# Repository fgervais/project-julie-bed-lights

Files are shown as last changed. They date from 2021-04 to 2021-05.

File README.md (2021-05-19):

# RGB LED Strip Controller

## Main Board
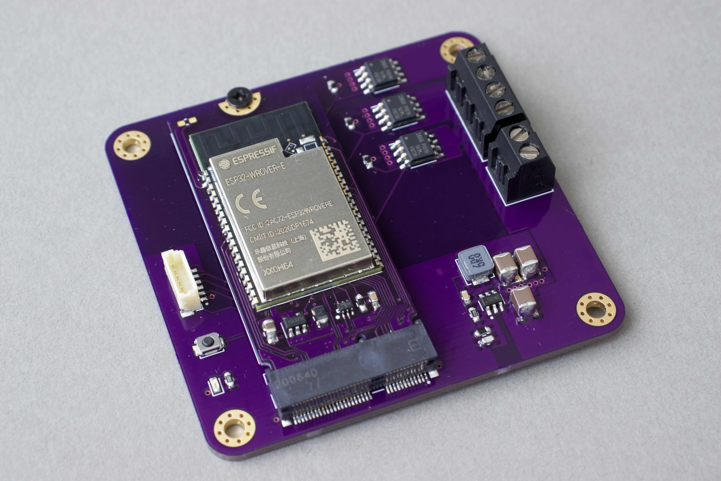
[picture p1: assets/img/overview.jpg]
Overview


## Early Tests with LED Strip
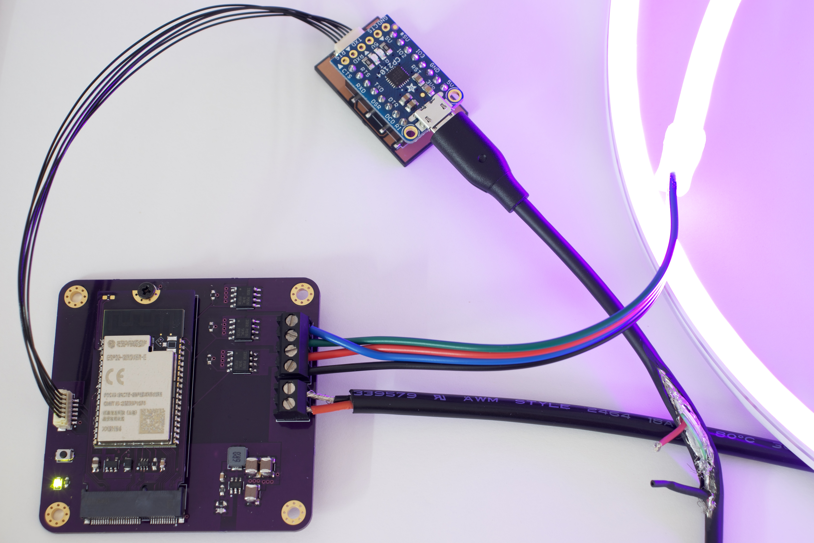
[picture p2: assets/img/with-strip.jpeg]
LED Strip


## Installed
Installed

## App

This project is entirely controlled through the phone app. 

The QR code can be used to get a copy of this Blink project.

Blynk Project | Blynk Project Clone QR
:-------------------------:|:-------------------------:
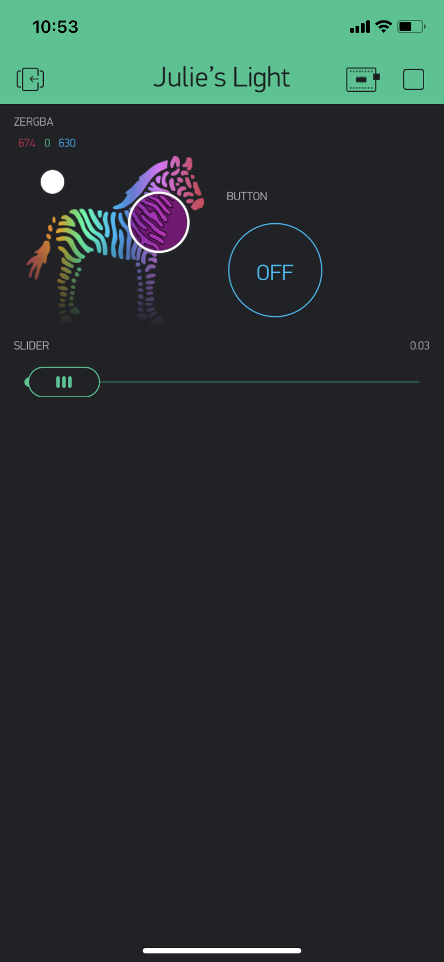
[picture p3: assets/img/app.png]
Blynk Project
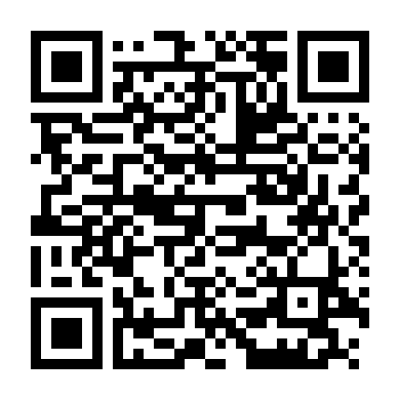
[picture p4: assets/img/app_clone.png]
Blynk Project QR
  |

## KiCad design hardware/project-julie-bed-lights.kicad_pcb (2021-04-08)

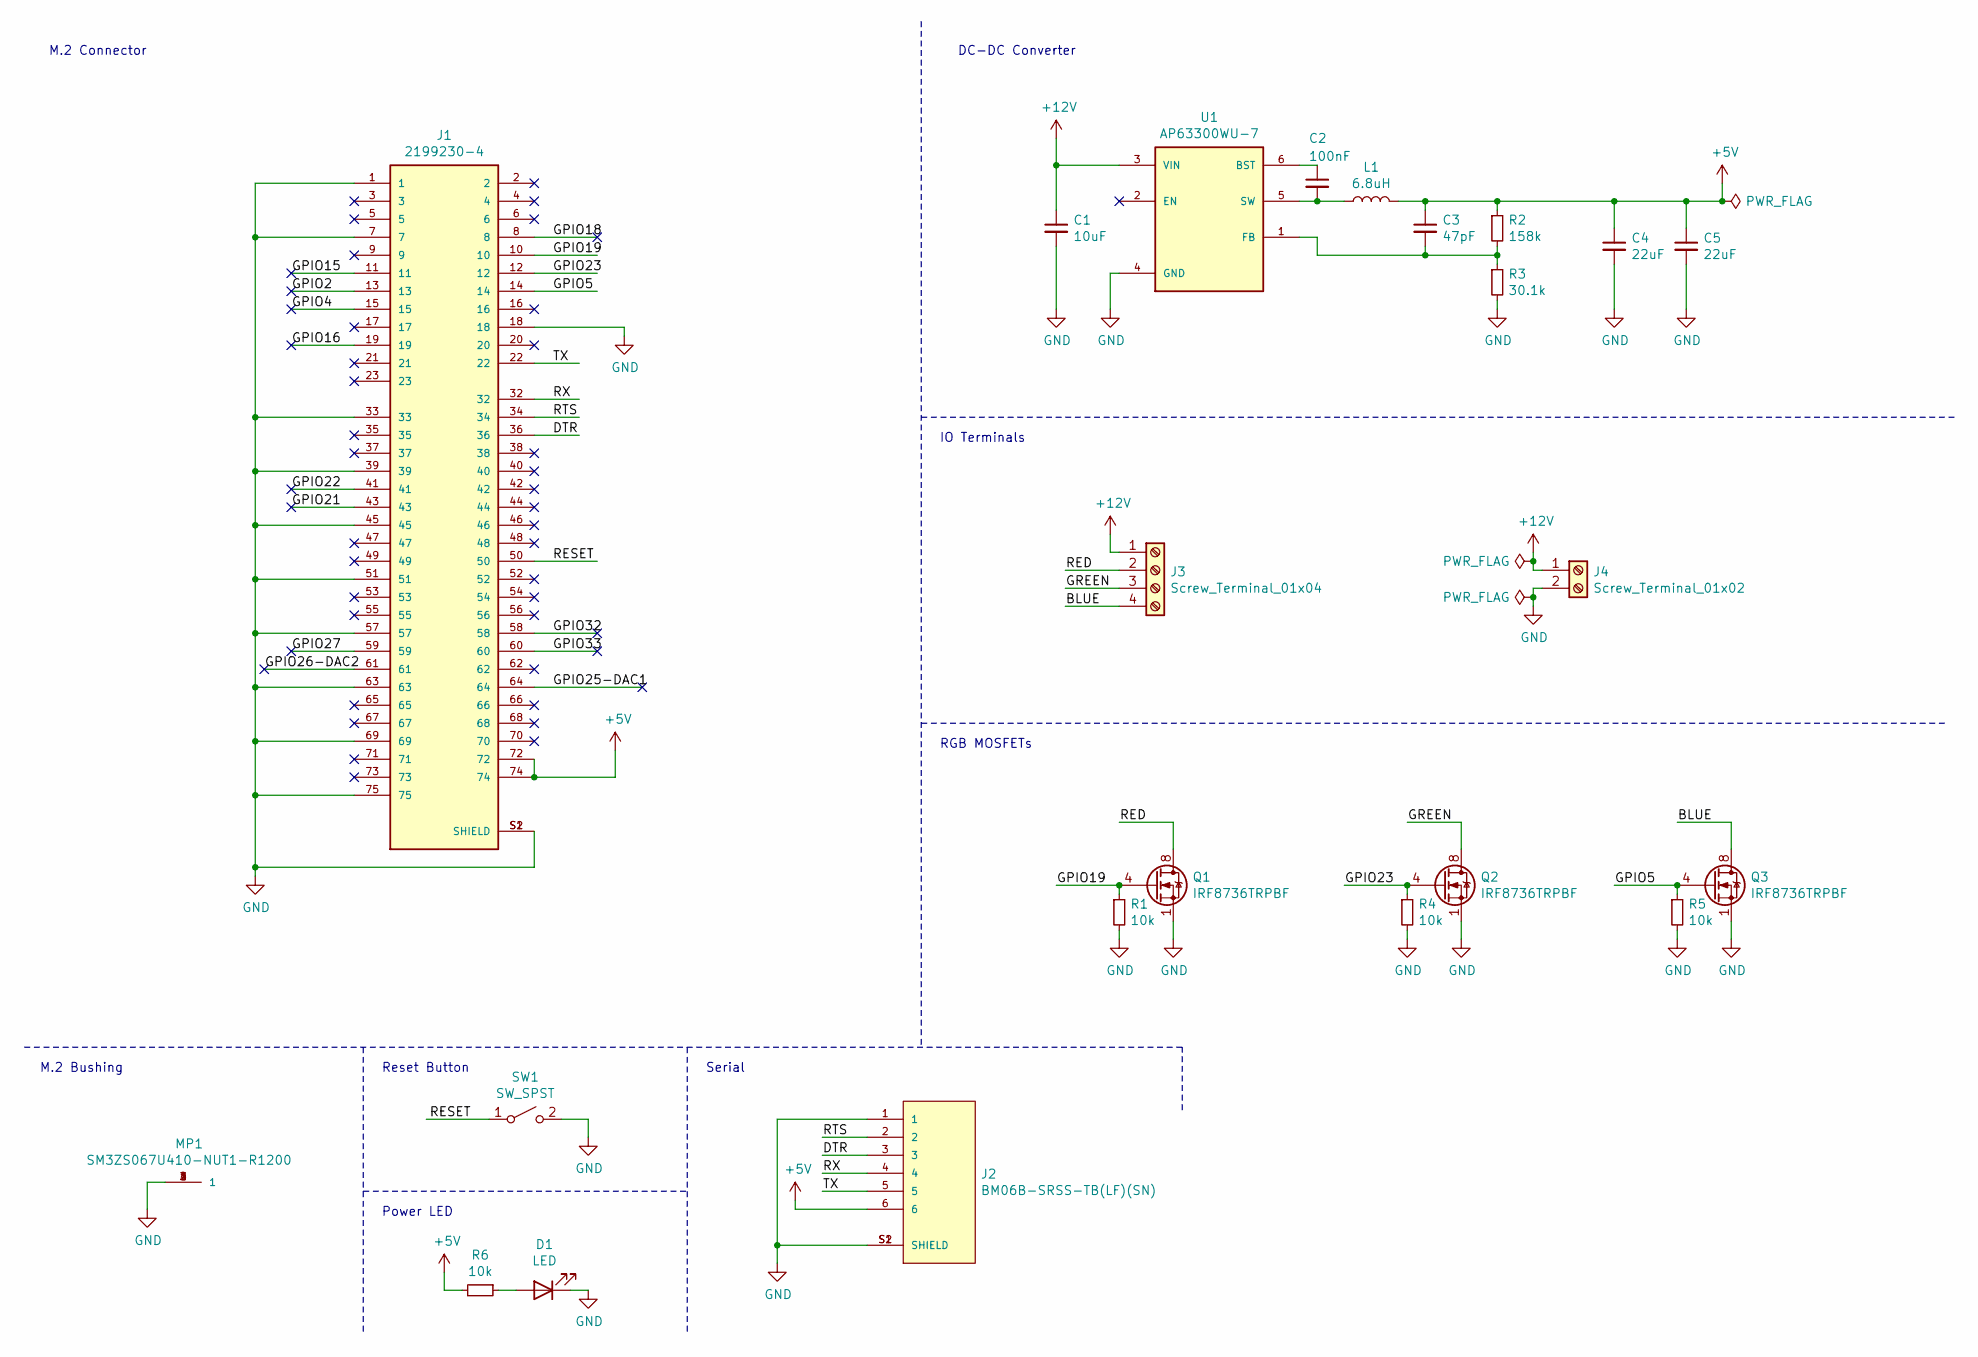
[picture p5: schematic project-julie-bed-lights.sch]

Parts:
C1: 10uF; C_1210_3225Metric_Pad1.33x2.70mm_HandSolder
C2: 100nF; C_0603_1608Metric
C3: 47pF; C_0603_1608Metric
C4, C5: 22uF; C_1210_3225Metric_Pad1.33x2.70mm_HandSolder
D1: LED; LED_0603_1608Metric
J1: 2199230-4; TE_2199230-4
J2: BM06B-SRSS-TB(LF)(SN); JST_BM06B-SRSS-TB(LF)(SN); PARTREV NA
J3: Screw_Terminal_01x04; Molex-393570004-MFG
J4: Screw_Terminal_01x02; Molex-393570002-MFG
L1: 6.8uH; IND_SRP4020TA-6R8M
MP1: SM3ZS067U410-NUT1-R1200; JAE_SM3ZS067U410-NUT1-R1200; PARTREV 2
Q1, Q2, Q3: IRF8736TRPBF‎; SOIC-8_3.9x4.9mm_P1.27mm
R1, R4, R5, R6: 10k; R_0603_1608Metric
R2: 158k; R_0603_1608Metric
R3: 30.1k; R_0603_1608Metric
SW1: SW_SPST; SW_SPST_B3U-1000P
U1: AP63300WU-7; SOT95P280X100-6N; PARTREV 2020-04-24

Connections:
+5V: C3.1, C4.1, C5.1, J1.72, J1.74, J2.6, L1.2, R2.1, R6.2
+12V: C1.1, J3.1, J4.1, U1.3 (VIN)
/BLUE: J3.4, Q3.5 (D), Q3.6 (D), Q3.7 (D), Q3.8 (D)
/DTR: J1.36, J2.3
/GPIO2: J1.13
/GPIO4: J1.15
/GPIO5: J1.14, Q3.4 (G), R5.1
/GPIO15: J1.11
/GPIO16: J1.19
/GPIO18: J1.8
/GPIO19: J1.10, Q1.4 (G), R1.1
/GPIO21: J1.43
/GPIO22: J1.41
/GPIO23: J1.12, Q2.4 (G), R4.1
/GPIO25-DAC1: J1.64
/GPIO26-DAC2: J1.61
/GPIO27: J1.59
/GPIO32: J1.58
/GPIO33: J1.60
/GREEN: J3.3, Q2.5 (D), Q2.6 (D), Q2.7 (D), Q2.8 (D)
/RED: J3.2, Q1.5 (D), Q1.6 (D), Q1.7 (D), Q1.8 (D)
/RESET: J1.50, SW1.1 (A)
/RTS: J1.34, J2.2
/RX: J1.32, J2.4
/TX: J1.22, J2.5
GND: C1.2, C4.2, C5.2, D1.1 (K), J1.1, J1.7, J1.18, J1.33, J1.39, J1.45, J1.51, J1.57, J1.63, J1.69, J1.75, J1.S1 (SHIELD), J1.S2 (SHIELD), J2.1, J2.S1 (SHIELD), J2.S2 (SHIELD), J4.2, MP1.1, MP1.2, MP1.3, MP1.4, Q1.1 (S), Q1.2 (S), Q1.3 (S), Q2.1 (S), Q2.2 (S), Q2.3 (S), Q3.1 (S), Q3.2 (S), Q3.3 (S), R1.2, R3.2, R4.2, R5.2, SW1.2 (B), U1.4 (GND)
unnamed: C2.1, U1.6 (BST)
unnamed: C2.2, L1.1, U1.5 (SW)
unnamed: C3.2, R2.2, R3.1, U1.1 (FB)
unnamed: D1.2 (A), R6.1

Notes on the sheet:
M.2 Bushing
Reset Button
Serial
DC-DC Converter
Power LED
M.2 Connector
IO Terminals
RGB MOSFETs

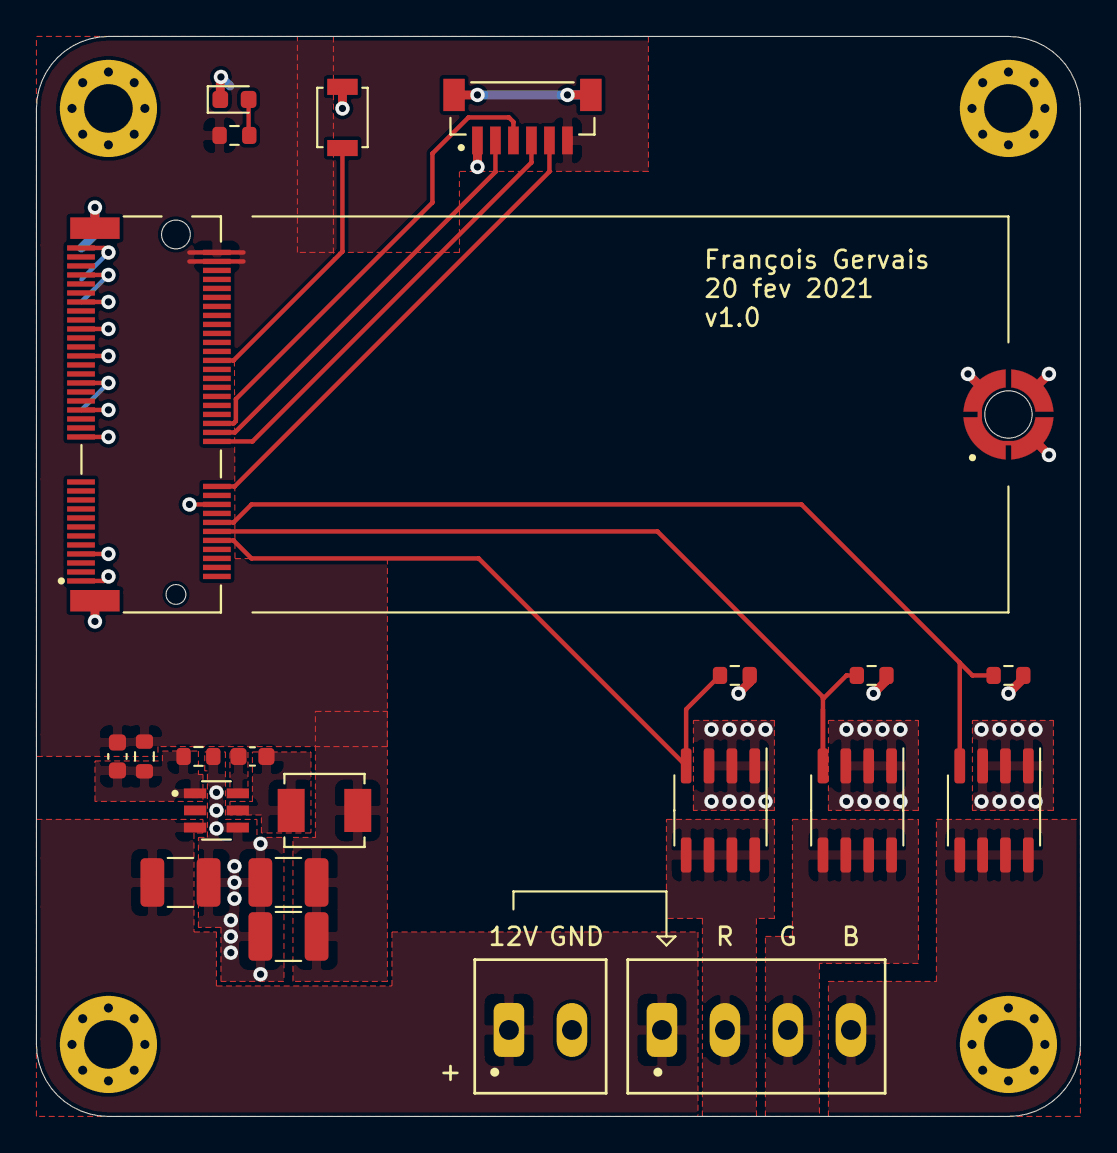
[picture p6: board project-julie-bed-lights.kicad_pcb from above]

Board: 2 copper layers, 58.0 x 60.0 mm, 23 parts (0 on the bottom side), 18 nets.

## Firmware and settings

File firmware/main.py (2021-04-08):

import network
import time
import micropython
import esp32
import machine
import blynklib_mp as blynklib
import blynklib_mp_ssl as blynklib_ssl
import secret

from machine import Pin, PWM, ADC, TouchPad, RTC, UART


RED_PIN = 19
GREEN_PIN = 23
BLUE_PIN = 5

COLOR_VPIN = 0
BRIGHTNESS_VPIN = 1
ON_OFF_VPIN = 2


wlan = network.WLAN(network.STA_IF)
wlan.active(True)
if not wlan.isconnected():
    print("connecting to network...")
    wlan.connect(secret.ESSID, secret.PSK)
    while not wlan.isconnected():
        time.sleep(1)
print("network config:", wlan.ifconfig())


class LedStrip:
    def __init__(self, rgb_pins):
        self.pwms = [PWM(Pin(i), freq=500, duty=0) for i in rgb_pins]
        self._on = False
        self._color = (0, 0, 0)
        self._brightnes = 0

    def on(self):
        self._on = True
        self.show()

    def off(self):
        self._on = False
        self.show()

    def show(self):
        if self._on:
            brightnes = self._brightnes
        else:
            brightnes = 0

        for index, value in enumerate(self._color):
            self.pwms[index].duty(int(value * brightnes))

    @property
    def color(self):
        return self._color

    @color.setter
    def color(self, value):
        self._color = value
        self.show()

    @property
    def brightnes(self):
        return self._brightnes

    @brightnes.setter
    def brightnes(self, value):
        self._brightnes = value
        self.show()


strip = LedStrip([RED_PIN, GREEN_PIN, BLUE_PIN])

ssl_connection = blynklib_ssl.SslConnection(secret.BLYNK_AUTH, port=443, log=print)
blynk = blynklib.Blynk(secret.BLYNK_AUTH, connection=ssl_connection)


@blynk.handle_event("write V" + str(COLOR_VPIN))
def write_handler(pin, value):
    strip.color = tuple(map(int, value))

@blynk.handle_event("write V" + str(BRIGHTNESS_VPIN))
def write_handler(pin, value):
    strip.brightnes = float(value[0])

@blynk.handle_event("write V" + str(ON_OFF_VPIN))
def write_handler(pin, value):
    if int(value[0]) == 1:
        strip.on()
    else:
        strip.off()


blynk.run()
for i in [COLOR_VPIN ,BRIGHTNESS_VPIN, ON_OFF_VPIN]:
    blynk.virtual_sync(i)
    blynk.run()

while True:
    blynk.run()

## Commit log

2021-02-07 Schematic done except DC-DC converter
    [project-julie-bed-lights.kicad_pcb, project-julie-bed-lights.sch]
2021-02-07 Added DC-DC converter
    [project-julie-bed-lights.sch]
2021-02-15 Test 3 PWMs
2021-02-19 First placement
    [project-julie-bed-lights.kicad_pcb, project-julie-bed-lights.sch]
2021-02-20 DC-DC converter routing
    [project-julie-bed-lights.kicad_pcb]
2021-02-20 First routing except ground
    [project-julie-bed-lights.kicad_pcb]
2021-02-21 First routing
    [project-julie-bed-lights.kicad_pcb]
2021-02-21 Add version of previous commit
    [project-julie-bed-lights.kicad_pcb]
2021-02-25 Fix Conn_Molex_39357000x footprint
    [project-julie-bed-lights.kicad_pcb]
2021-03-31 Setup assembly print
    [project-julie-bed-lights.kicad_pcb, project-julie-bed-lights.sch]
2021-04-01 Add polarity marking on power input
    [project-julie-bed-lights.kicad_pcb]
2021-04-08 Fix app sync on boot
    [main.py]
2021-04-08 Change pwm freq to 500Hz
2021-04-08 Add screw terminal marking
    [project-julie-bed-lights.kicad_pcb]
2021-04-09 Add image with led strip
2021-09-20 Add basic esphome project
    [partitions.csv]
2021-09-24 Remove pin comment
